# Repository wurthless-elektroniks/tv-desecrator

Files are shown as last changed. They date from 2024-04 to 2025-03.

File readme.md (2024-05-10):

# TV Desecrator: A universal-as-I-can-make-it RGB SCART circuit for non-SCART TVs

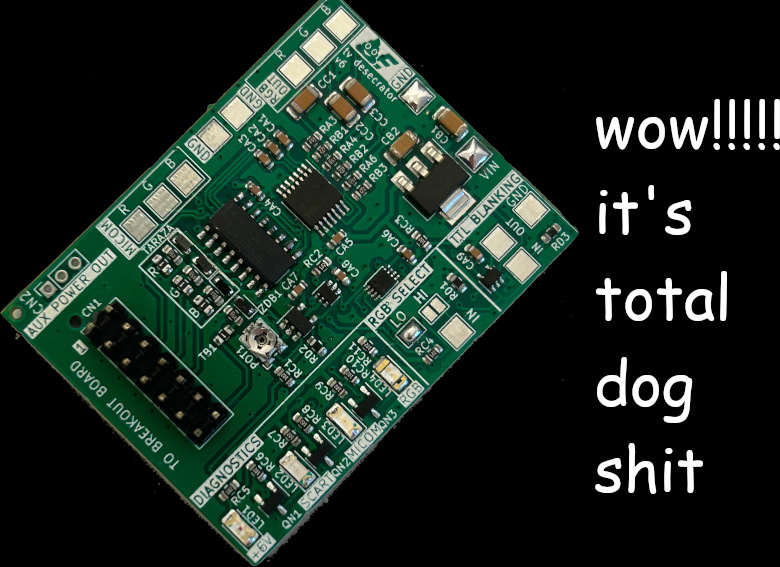
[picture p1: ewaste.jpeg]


Hey, you! Are you an idiot who wishes to ruin a perfectly good TV? Then build yourself a TV Desecrator! It's a reliable way of adding a SCART connector to a TV that doesn't normally support it.

There are plenty of takes on RGB mods already, but I wanted to do one with seamless operation and simpler installation. In other words, I wanted the SCART connector to behave as if it was part
of the TV set rather than a bolt-on feature. A hell of a challenge for someone with next to no knowledge of electronics, but totally worth it in the end as long as I get to stick it to the other
modders and hopefully make a few bucks while I'm at it.

This is all discrete logic so you only get the Gerbers.

The TV Desecrator is part of the wider Jänkermeister's CRT Toolkit project, which also includes:
* The [G1 Crymax](https://github.com/wurthless-elektroniks/g1crymax)
* The [simple SCART breakout board](https://github.com/wurthless-elektroniks/scart-breakout)
* ...and possibly others

# WARNING - STILL UNDER CONSTRUCTION

TV Desecrator v6 is still undergoing testing and is not guaranteed to work correctly. Think of this as an open betatest with nobody participating (except for me).
If you order your own boards and find it doesn't work, then you forgot to read this caveat emptor.

# Features

* SCART port can function exactly like a normal input; totally switchless operation
* RGB injection that doesn't interfere with OSD and other input modes
* Safe and reliable SCART RGB blanking detection: no need to worry about 10 volt signals wrecking shit
* Much easier installation than passive diode mux mods: abacus not required
* THS7374 video amp so the final injected signal comes in loud and clear
* Diagnostic blinkenlights to tell you where you fucked up
* Modular design so you can easily pull the TV case apart when things inevitably explode
* Modular design also means you can use BNC or JP-21 like a civilized person

# **BEFORE YOU INSTALL THIS, ASK YOURSELF: "DO I REALLY NEED RGB?"**

Chances are you don't. People often use RGB to compensate for poorly tuned equipment. You can get a great picture without ever having to use RGB.
To do so, perform some combination of the following steps:

* Recap entire set, particularly anything related to the power supply, horizontal/vertical deflection circuits, RGB drives, and most importantly the NTSC decode circuitry
* Recalibrate colors, drives and cutoffs if possible
* Drop G1 pin to a negative voltage and recalibrate SCREEN and FOCUS to get a sharper picture and better contrast (*this is a must on larger sets!*)
* Use component or S-Video if available (they don't suffer from composite color artifacts)
* Use a console that outputs better quality video than others in its class (in Sega Genesis terms, throw your Model 2 in the garbage and get a Model 1)

Other options for RGB gaming, besides modding old TVs, include:
* Computer monitors that support 15 kHz natively
* The usual 15 kHz to whatever-standard-you-please converters (shitty GBS converters, SCART to component, OSSC, etc.)
* If you want to live dangerously, an arcade monitor with an amp and sync stripper. (Some oldschool consoles output TTL RGB natively, you just need to know how to tap it.)

Remember: **DO NOT RGB MOD A TV SET UNLESS YOU REALLY NEED TO** <sup><sub>(or just want to scam idiot retro gamers)</sub></sup>

# Schematic

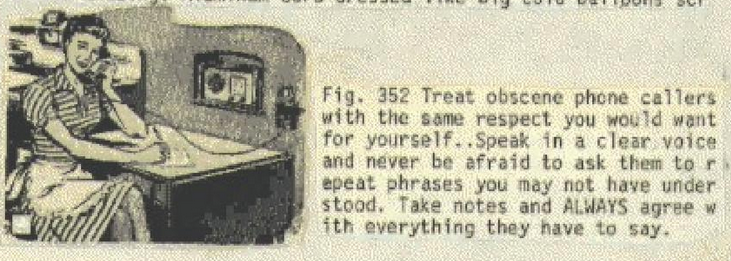
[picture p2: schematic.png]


There are two major parts of the circuit. The first is logic circuitry that determines when the RGB signal coming in from the SCART connector should
be sent to the TV; if not allowed, it selects the MICOM inputs. The second is a switcher and amplification circuit that allows the TV Desecrator
to appear to the TV as if it were a normal, everyday MICOM. The rest is all boring and not worth explaining here.

Please read the extensive documentation to learn about how this thing works, how to install it, and known issues.

## License

Public domain

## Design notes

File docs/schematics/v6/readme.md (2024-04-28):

# TV Desecrator v6 schematics

This is what happens when a guy with a lot of money and no electronics expertise designs a circuit board. I'm writing this to explain how
the circuit works and also why I chose to implement the circuit this way.

## Power supply

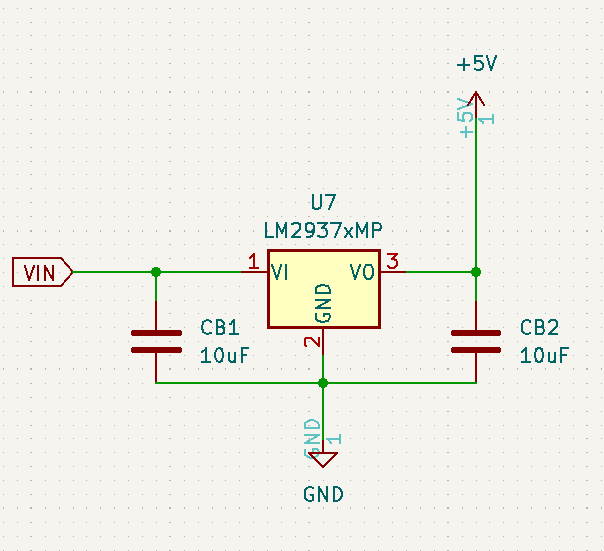
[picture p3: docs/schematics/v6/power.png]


The TV Desecrator runs at +5V. Although many TVs have a +5V rail (or +5.6V) for the MICOM circuit, I've found that the voltage regulators aren't
really meant to drive anything other than a standby load, and, being standby rails, are on all the time. So the TV Desecrator has a voltage regulator
onboard that's tied to some lower-voltage DC doohickery on the chassis. The voltage regulator is a LM2937IMP-5.0 or pin-compatible replacement.
Two 10uF ceramic caps stabilize the voltage going in and out of the regulator. Boring stuff, really.

## RGB inputs

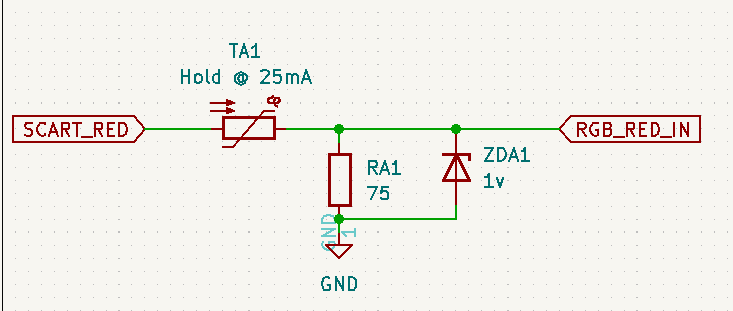
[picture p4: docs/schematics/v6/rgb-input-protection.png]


RGB comes in off whatever device we have, then each channel goes through a PTC resettable fuse, has the 75 ohm pulldown applied, and is forwarded off
to the switcher. A zener (nominally 1V but can be 2V) is used to clamp the signal to ground in case of overvoltage.

Protecting the TV chassis is mission critical, and here's the first line of defense, where I at least try to prevent this. The idea is that if voltages
go too high, then the zeners will start clamping and drawing a few too many milliamps, causing the PTC fuses to stop the show. I had lost one TV to
JAMMA-level voltages and I wasn't about to let it happen again.

## SCART blanking voltage detection

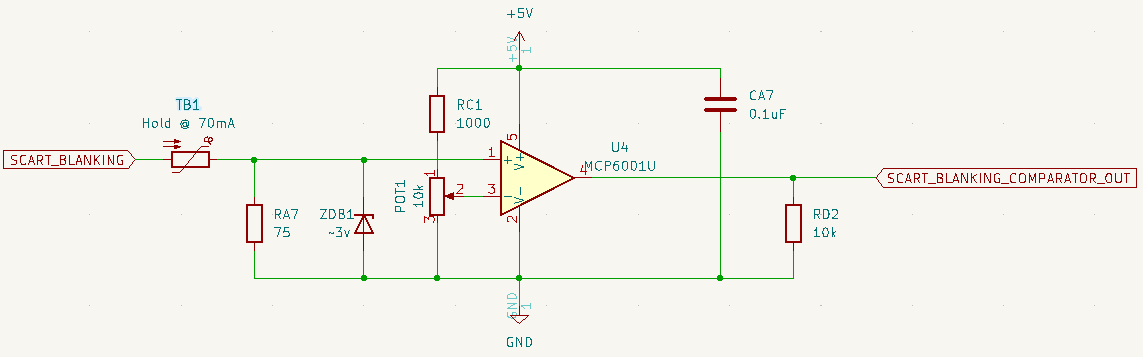
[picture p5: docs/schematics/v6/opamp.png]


This is where things get a little weird. I used an op-amp to detect the SCART blanking voltage mostly because of the odd voltages that could be
coming in on that line. It's supposed to be 75 ohm terminated, which I honored here, but even then the voltage might not be enough to trigger
the CMOS logic. Also, when I did my reading on typical SCART implementations, I read that some systems might use voltages higher than the 1-3VDC
that are typically present on this pin in RGB mode.

The reference voltage for the op-amp is set via a 10k potentiometer. It should be calibrated to as close to 1VDC as possible. Virtually every SCART
spec you'll find online says that a blanking voltage of 1-3VDC indicates RGB.

The blanking signal comes in through another PTC resettable fuse and is 75-ohm terminated, with a zener (nominally 5.6VDC) keeping watch over this
side of the circuit, because anything above 6 volts or so will make the op-amp very sad to the point where it kills itself. Upon going above the
reference voltage (which, again, should be 1VDC), the op-amp outputs a logical high signal; at all other times it is a logical low signal. This
signal is called SCART_BLANKING.

## RGB muxer logic

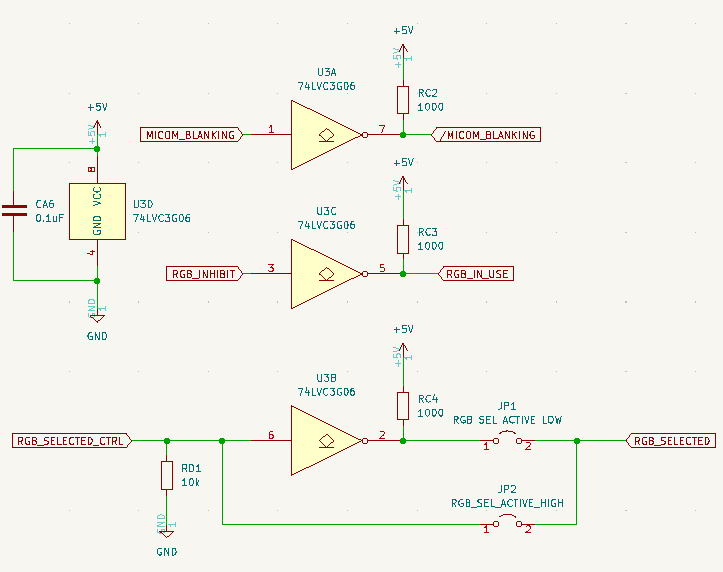
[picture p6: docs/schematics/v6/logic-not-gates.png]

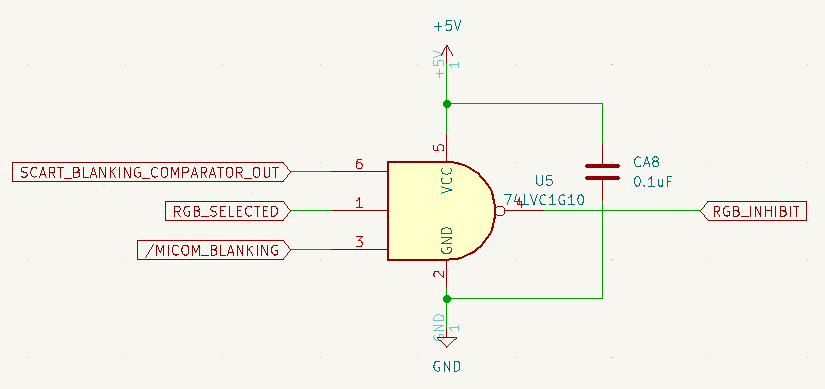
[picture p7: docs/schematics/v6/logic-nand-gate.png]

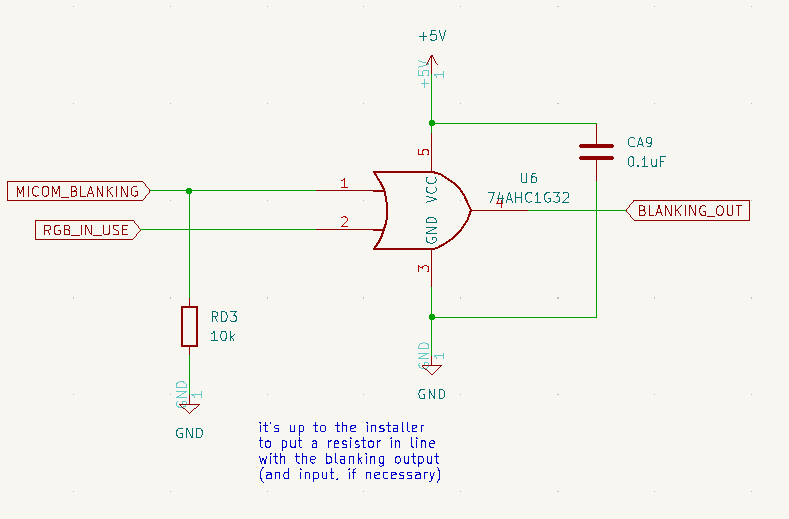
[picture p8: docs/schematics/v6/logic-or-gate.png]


This ratsnest of logic computes:

    RGB_INHIBIT = !(SCART_BLANKING && RGB_SELECTED && !MICOM_BLANKING)
    RGB_IN_USE = !RGB_INHIBIT
    BLANKING_OUT = (RGB_IN_USE || MICOM_BLANKING)

This is done entirely using discrete 74-series logic chips, but could be unified into a single chip. As of yet, though, virtually
every single chip option would either be too expensive, overpowered, unreliable, or not +5VDC compatible.

Of particular interest is the RGB_SELECTED signal. This is a logical input from some other device indicating that the TV is set to the
right input and is ready for our RGB signal. This is something of a departure from other RGB muxer mods, which simply don't implement
this because there are too many cases to account for. That would add complexity, so I simplified it down to a single input and left it at
that. Jumpers on the board set this signal to active high (goes directly to the chips), or active low (input goes via an inverter).

## Switcher phase

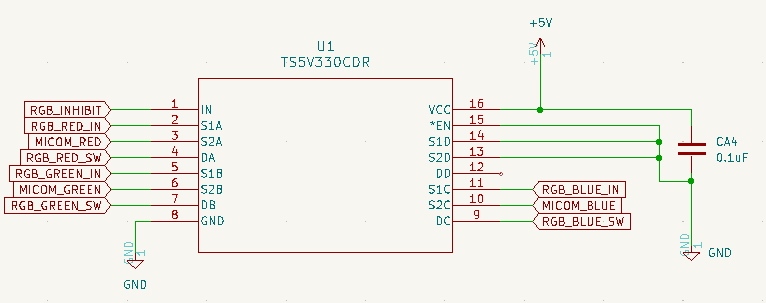
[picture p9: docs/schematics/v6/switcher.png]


RGB switching is performed by a TS5V330CDR 4-channel video switch. By default the switch allows the MICOM signal through, as RGB_INHIBIT
will normally drive the select pin high. When RGB_INHIBIT falls, the injected RGB signal passes through to the final output phase.

## Final output phase

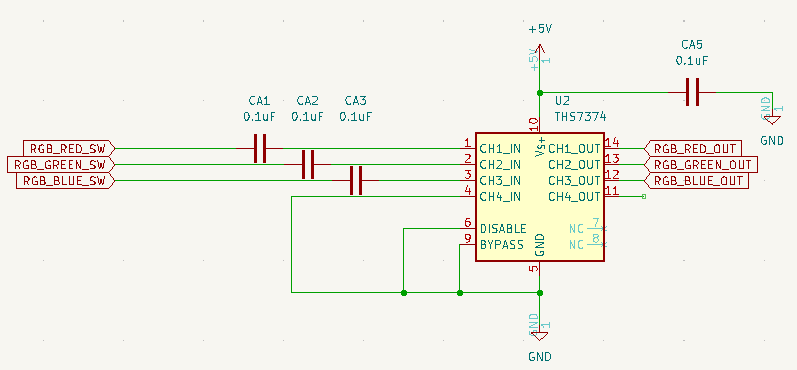
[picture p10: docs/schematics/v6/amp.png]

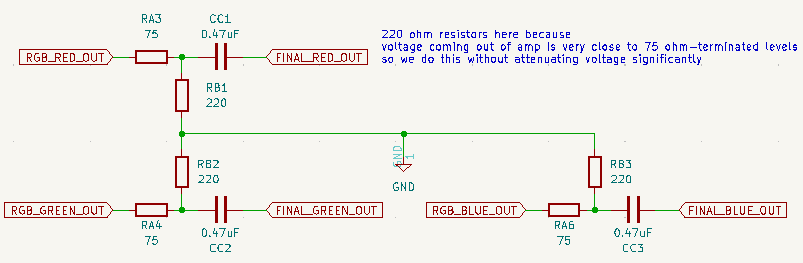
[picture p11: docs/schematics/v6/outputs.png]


The switched video goes through a THS7374, which I'm abusing here as a buffer. Since this circuit is functionally isolated from the
main RGB lines, we have to do the usual 75 ohm pulldown dance and buffer capacitor on the end. The pulldown is 220 ohms, which seems
odd but has been chosen to prevent the output RGB voltages from being halved, as they will be slightly above the 0.7VDC RGB levels by
the time they exit the amplifier. The caps are 0.47uF, chosen because they were a known value in my JVC, but had also been found to work
on other sets.

The THS7374 was originally added to the design because whatever switching logic would be in place would likely attenuate the signal
somewhat. The disable and lowpass features are not used at all; those pins are simply tied to ground. The obvious improvement here
is to replace it with a far cheaper chip, but this is the one I'm used to, so I'm just doing what I know works.

## Diagnostic lights

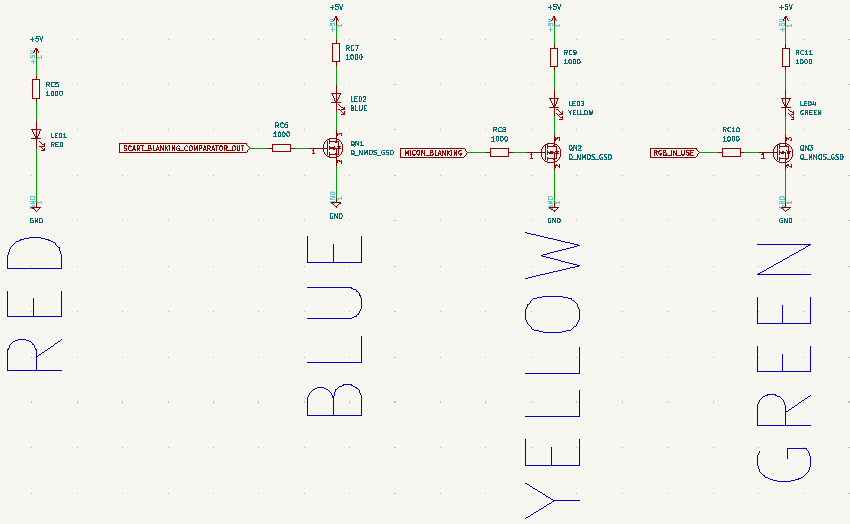
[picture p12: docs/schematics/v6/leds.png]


Finally there are the four diagnostic LEDs. They are:

* RED = +5V (power present)
* BLUE = SCART (SCART blanking signal detected)
* YELLOW = MICOM (MICOM blanking signal detected)
* GREEN = RGB (RGB in use)

All of the LEDs are current-limited using 1k resistors, which is enough to turn them on at non-obnoxious levels. The red LED is on all
the time as it's tied to the power supply. The others are all switched with N-channel MOSFETs so as not to drag the I/O logic low.
It's obvious that this design formerly used NPN transistors as the resistors limiting base current (sorry, *gate* current) are still there.
These resistors are most likely useless now and will be removed in future revisions.

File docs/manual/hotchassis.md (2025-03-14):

# The perils of hot chassis

This is a must-read for anyone attempting to modify any CRT TV or display, as it's important
for health and safety.

The TV Desecrator was designed only for television sets that are properly isolated from the mains.
I didn't really know about the hazards of hot chassis at the time, but now that I do, and have made
a very expensive computer (a Mac Studio) explode as part of this lesson, I'm writing this document to advise all
prospective modders about hot chassis, how to identify them, and the dangers of modifying them.

**The tl;dr is: NEVER attempt to modify a hot chassis. You will kill your expensive equipment and
potentially yourself.**

## What's a hot chassis?

A hot chassis is any CRT chassis where the low voltage side is directly referenced to the mains.
These tend to be seen on older or "budget" designs, where proper isolation is not required and they
assume you won't be fiddling around inside of the set.

## Identifying a hot chassis

Here are some ways of identifying a hot chassis.

1. **No transformer besides the flyback**: This is the easiest way of detecting a hot chassis.
   Trace the low voltage power supply back as far as you can go. If you don't see that it's connected
   to a switching power supply, or that there's a dropper resistor or similar knocking the voltage down
   to something the low voltage regulators can handle, then it's a hot chassis.

2. **RF-only sets**: Not always a sign you're dealing with a hot chassis but a good indicator. RF-only
   sets only need to expose one piece of metal (the RF jack) so the designs aren't concerned at all with
   safely isolating the chassis. **The tell-tale sign is whether the tuner directly terminates with a
   coax connector.** If the coaxial connector is on its own box, then that's a sign the RF input is using
   a balun to isolate the coax lead from the chassis.

3. **Chassis "ground" connected to AC neutral**: Usually on a hot chassis a resistor is all that separates chassis "ground"
   from AC neutral. Check what resistance there is between ground and the AC neutral connection; there shouldn't
   be any. On one Orion set I tested, the resistor separating chassis "ground" and neutral was approximately 16k ohms.

Note that on switching power supplies, there may be class Y capacitors tying the supposedly isolated side
with the mains. This is normal. 

## Hazards

If you attempt to modify or otherwise play with a hot chassis, you run the risk of the following:

* Any equipment you connect, including your treasured and very expensive electronics or test equipment, will likely explode
* Electrical shock and possible electrocution
* Smoke and fire

## What if I want to make a hot chassis safe?

That's not worth the cost. You'll need to isolate pretty much every input from the SCART connector, so that's
4 video signals plus two audio signals. Combine that with the fact you need specialist baluns for isolation
and you'll have a sizeable bill.

This is also the reason why you shouldn't try modifying a RF-only chassis to support RCA inputs. I had to give
up on that dream when I realized it wasn't feasible compared to SCART modding.

Save yourself the headache and find a properly isolated set.

**If, however, you ever need to work on a hot chassis as part of a repair job, an isolation transformer and
battery-operated equipment will limit the risk of zaps, ouchies and kabooms.**

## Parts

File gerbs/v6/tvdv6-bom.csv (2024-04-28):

Item | Qty | Reference(s) | Value | LibPart | Footprint | Datasheet | DNP | LCSC
1 | 9 | CA1, CA2, CA3, CA4, CA5, CA6, CA7, CA8, CA9 | 0.1uF | Device:C | Capacitor_SMD:C_0603_1608Metric | ~ |  | C30926
2 | 2 | CB1, CB2 | 10uF | Device:C | Capacitor_SMD:C_1206_3216Metric | ~ |  | C2911380
3 | 3 | CC1, CC2, CC3 | 0.47uF | Device:C | Capacitor_SMD:C_1206_3216Metric | ~ |  | C518885
4 | 1 | CN1 | SCART RGB CTL | Connector_Generic:Conn_02x07_Odd_Even | Connector_PinHeader_2.54mm:PinHeader_2x07_P2.54mm_Vertical | ~ |  | C71397
5 | 1 | CN2 | AUX POWER | Connector_Generic:Conn_01x03 | Connector_PinSocket_2.00mm:PinSocket_1x03_P2.00mm_Vertical | ~ |  | C18723059
6 | 1 | JP1 | RGB SEL ACTIVE LOW | Jumper:Jumper_2_Open | Jumper:SolderJumper-2_P1.3mm_Open_Pad1.0x1.5mm | ~
7 | 1 | JP2 | RGB_SEL_ACTIVE_HIGH | Jumper:Jumper_2_Open | Jumper:SolderJumper-2_P1.3mm_Open_Pad1.0x1.5mm | ~
8 | 1 | LED1 | RED | Device:LED | Diode_SMD:D_1206_3216Metric | ~ |  | C273626
9 | 1 | LED2 | BLUE | Device:LED | Diode_SMD:D_1206_3216Metric | ~ |  | C965827
10 | 1 | LED3 | YELLOW | Device:LED | Diode_SMD:D_1206_3216Metric | ~ |  | C93094
11 | 1 | LED4 | GREEN | Device:LED | Diode_SMD:D_1206_3216Metric | ~ |  | C2980185
12 | 1 | POT1 | 10k | Device:R_Potentiometer | Potentiometer_SMD:Potentiometer_Bourns_TC33X_Vertical | ~ |  | C719176
13 | 3 | QN1, QN2, QN3 | Q_NMOS_GSD | Device:Q_NMOS_GSD | Package_TO_SOT_SMD:SOT-23-3 | ~ |  | C414015
14 | 7 | RA1, RA2, RA3, RA4, RA5, RA6, RA7 | 75 | Device:R | Resistor_SMD:R_0603_1608Metric | ~ |  | C325592
15 | 3 | RB1, RB2, RB3 | 220 | Device:R | Resistor_SMD:R_0603_1608Metric | ~ |  | C269445
16 | 11 | RC1, RC2, RC3, RC4, RC5, RC6, RC7, RC8, RC9, RC10, RC11 | 1000 | Device:R | Resistor_SMD:R_0603_1608Metric | ~ |  | C3017736
17 | 3 | RD1, RD2, RD3 | 10k | Device:R | Resistor_SMD:R_0603_1608Metric | ~ |  | C2074749
18 | 3 | TA1, TA2, TA3 | Hold @ 25mA | Device:Thermistor_PTC | Resistor_SMD:R_0603_1608Metric | ~ |  | C883088
19 | 1 | TB1 | Hold @ 70mA | Device:Thermistor_PTC | Resistor_SMD:R_0603_1608Metric | ~ |  | C883088
20 | 1 | TP1 | MICOM RED | Connector:TestPoint | TestPoint:TestPoint_Pad_2.5x2.5mm | ~
21 | 1 | TP2 | MICOM GREEN | Connector:TestPoint | TestPoint:TestPoint_Pad_2.5x2.5mm | ~
22 | 1 | TP3 | MICOM BLUE | Connector:TestPoint | TestPoint:TestPoint_Pad_2.5x2.5mm | ~
23 | 1 | TP4 | BLNK IN | Connector:TestPoint | TestPoint:TestPoint_Pad_2.5x2.5mm | ~
24 | 1 | TP5 | BLNK OUT | Connector:TestPoint | TestPoint:TestPoint_Pad_2.5x2.5mm | ~
25 | 1 | TP6 | VIN | Connector:TestPoint | TestPoint:TestPoint_Pad_2.5x2.5mm | ~
26 | 1 | TP7 | RGB SELECTED | Connector:TestPoint | TestPoint:TestPoint_Pad_2.5x2.5mm | ~
27 | 1 | TP8 | FINAL RED | Connector:TestPoint | TestPoint:TestPoint_Pad_2.5x2.5mm | ~
28 | 1 | TP9 | FINAL GREEN | Connector:TestPoint | TestPoint:TestPoint_Pad_2.5x2.5mm | ~
29 | 1 | TP10 | FINAL BLUE | Connector:TestPoint | TestPoint:TestPoint_Pad_2.5x2.5mm | ~
30 | 4 | TP11, TP12, TP13, TP14 | GND | Connector:TestPoint | TestPoint:TestPoint_Pad_2.5x2.5mm | ~
31 | 1 | U1 | TS5V330CDR | TS5V330CDR:TS5V330CDR | TS5V330CDR:D16 | TS5V330CDR |  | C2652482
32 | 1 | U2 | THS7374 | Amplifier_Video:THS7374 | Package_SO:TSSOP-14_4.4x5mm_P0.65mm | https://www.ti.com/lit/ds/symlink/ths7374.pdf |  | C2652746
33 | 1 | U3 | 74LVC3G06 | 74xGxx:74LVC3G06 | Package_SO:VSSOP-8_2.4x2.1mm_P0.5mm | http://www.ti.com/lit/sg/scyt129e/scyt129e.pdf |  | C548744
34 | 1 | U4 | MCP6001U | Amplifier_Operational:MCP6001U | Package_TO_SOT_SMD:SOT-23-5 | http://ww1.microchip.com/downloads/en/DeviceDoc/21733j.pdf |  | C21403
35 | 1 | U5 | 74LVC1G10 | 74xGxx:74LVC1G10 | Package_TO_SOT_SMD:SOT-363_SC-70-6 | http://www.ti.com/lit/sg/scyt129e/scyt129e.pdf |  | C460523
36 | 1 | U6 | 74AHC1G32 | 74xGxx:74AHC1G32 | Package_TO_SOT_SMD:SOT-353_SC-70-5 | http://www.ti.com/lit/sg/scyt129e/scyt129e.pdf |  | C460492
37 | 1 | U7 | LM2937xMP | Regulator_Linear:LM2937xMP | Package_TO_SOT_SMD:SOT-223-3_TabPin2 | http://www.ti.com/lit/ds/symlink/lm2937.pdf |  | C42249
38 | 3 | ZDA1, ZDA2, ZDA3 | 1v | Device:D_Zener | Diode_SMD:D_0603_1608Metric | ~ |  | C7081529
39 | 1 | ZDB1 | ~3v | Device:D_Zener | Diode_SMD:D_0603_1608Metric | ~ |  | C7403907

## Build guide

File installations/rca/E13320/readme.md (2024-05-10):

# RCA E13320

Lovely 13" slot mask TV from RCA.

Tube: 37GDA86X (slot mask)

Points of interest:
- CV505, CV507, CV509 are the RGB caps
- RR40: Red channel TTL-to-0.7V dropdown resistor
- RR39: Green channel TTL-to-0.7V dropdown resistor
- RR38: Blue channel TTL-to-0.7V dropdown resistor
- RR41: Blanking resistor

Switchless operation only possible via sync comparison or I2C snooping.

[Sunthar's diode mux diagram](https://sector.sunthar.com/guides/crt-rgb-mod/rca-e13320.html) was a big help here.

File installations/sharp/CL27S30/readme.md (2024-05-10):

# Sharp CL27S30

Consumer grade TV with S-Video, two video inputs, and picture-in-picture.

Tube: Thomson A68ADT25X-06 (shadow mask)

Points of interest:
- C804 = red capacitor
- C805 = green capacitor
- C806 = blue capacitor
- Jumper 417 = blanking from MICOM to jungle IC
- C408 = 7 volts smoothing cap

Switchless operation still TODO.

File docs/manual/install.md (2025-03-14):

# Installation

## Identifying a RGB-capable set

Find a CRT TV matching these specifications:
- Manufacture date in the 1990s or 2000s
- Must have composite video input, **preferably only one video input**
- Must have on-screen display
- Sets with component and composite on the same video input are of particular interest (I'll explain why)
- **Chassis MUST be properly isolated from the mains (read [hotchassis.md](hotchassis.md)). NEVER attempt to
  modify a hot chassis.**

Once you have found your TV of choice, open it up and study the circuitry. You are looking for the following:
- MICOM chip: a microcontroller looking thingy near the front panel controls.
  It receives power in standby (typically +5V) and will have an integrated RGB video output.
  Near the MICOM, you will find...
- TTL to 0.7V (1Vpp) RGB conversion circuit, which is usually nothing more than three voltage dividers
  for each of the RGB channels. Usually identifiable by a trio of 4.7k resistors close to the MICOM.
- The blanking control circuit, which the MICOM chip uses to take priority over the NTSC output.
  This is typically +5V at the source, but is often knocked down to a lower voltage.
- The RGB in-line capacitors. There will be three of them, and they will all be the same value.
  In many cases they will be surface mount caps right next to the inputs on the jungle chip.
  However it's common for these caps to be electrolytics.
- And, most importantly, the jungle chip, which is an all-in-one chip that decodes NTSC signals,
  overlays the OSD, and drives the RGB signals on the CRT itself.

The TV Desecrator is NOT compatible with the following types of TV chassis:
- All-in-one MICOM/jungle chip with no external RGB inputs
- MICOM logic operating at 3.3VDC (the TV Desecrator assumes 5VDC)
- Jungle chips that use "digital" RGB inputs, or any RGB signal that isn't 0.7V

**TVs from the 1980s and earlier will NEVER be supported.** Their circuitry is all analog, the picture they
produce is inferior to the more modern sets, and they have massive retro and collector appeal that will be
dashed the second you graft a SCART connector onto them. Plus which, RGB video can't be used to drive
the electron guns directly. Leave those sets for the collectors and restoration guys. They'll thank you for it.

Note that some TVs have composite and component signals coming in on the same video input (Toshiba sets call
the input "COLOR STREAM"). The jungle chip on those sets *might* have a pin that toggles the component lines
between YPbPr and RGB. **These sets aren't supported by this mod, but I might tackle them as a separate project one day.**

And, most importantly, **test your TV in full before modding it!** That way you'll know how it's supposed to work.

## Testing procedure

Before you hack apart your TV, you'll need to test it in full. If you have the remote control, that's great news because you'll be
able to go into service menus if your set has any.

Connect as many video sources as possible to see how the set behaves with a given input. Play around with some games to try
to get the image to distort. Make notes on how every OSD screen behaves. Take pictures and video if need be.

Also check how audio input is handled with RCA stereo connections. When you have only the left channel plugged in, does it play
over both speakers? If you connect a dummy input to the right channel input, does the right channel mute?

**Remember: All of the information you gather before even opening the set will help you in the long run.**

## Forming the plan of attack

By the time your TV is in pieces on the floor of your studio apartment and you've gotten to this sentence,
you have without a doubt have read the schematics. Thus you will know that **the TV Desecrator sits between the
MICOM and jungle chips, allowing RGB in from a SCART video source when it is allowed**. This provides the
challenge that you now face during the installation.

The general installation procedure is:

- The **TTL-level (+5V) blanking signal** must be rerouted to the TV Desecrator, and the TV Desecrator's mixed blanking
  signal must be returned in its place. There is typically a resistor limiting current from the MICOM's blanking pin
  to the jungle chip's input, usually around 1.5k to 2k. Measure this resistor, then put an equivalent resistor in line
  from the TV Desecrator's blanking output. Failure to do this will cause problems, such as OSD colors/black levels being
  incorrect.
- The **0.7V-level RGB signals prior to the capacitors** must be rerouted to the TV Desecrator, and the TV Desecrator's
  multiplexed RGB signals must be returned to the opposite end of where the capacitors formerly sat.
- A suitable DC power source must be located to power the 5 volt voltage regulator on board the TV Desecrator. Though many
  sets have a +5V power source, it's designed only to run the MICOM and is on all the time (i.e., in standby).

The TV Desecrator does not carry composite video or audio, but you'll have to get them out of the SCART connector and route
them as follows:
- The composite video signal must go to the composite video input. This is trivial. I don't even know why it was worth mentioning.
- The audio inputs must go to the... well, the audio inputs. If your set is mono, mix the two guys together with resistors.
  If your set stays in mono mode no matter what you do, it's because the RCA jacks have an internal switch that is toggled when
  you stick something in there. You might need to hack the RCA connectors to get around this limitation.

This is difficult already, but now you have to deal with the most annoying thing of all...

## Knowing when to inject RGB

Also called "why every RGB modder just uses a switch".

RGB_SELECTED is a signal that, when active, will get the TV Desecrator injecting RGB video. It can be set as
active high (jump HI) or as active low (jump LO); the input is always pulled low via a 10k resistor.

Recall that RGB video is injected if and only if:
- 1. the SCART blanking signal has been detected,
- 2. the MICOM is not displaying anything (MICOM_BLANKING is low), and
- 3. RGB_SELECTED is active (somehow)

Or, in boolean terms:

    RGB_IS_ACTIVE = !RGB_INHIBIT = !(SCART_BLANKING && !MICOM_BLANKING && RGB_SELECTED)

So how do you find the RGB_SELECTED signal? Here are some ideas.

### Trivial difficulty: Always on

Jump LO and let RGB_SELECTED float. Pulldown resistors will do their job. RGB will always be injected
as long as conditions 1. and 2. are met. And that will obviously cause interference when you switch video inputs.

In short, this makes the TV Desecrator behave like a normal diode mux mod. 

### Easy difficulty: The Switch of Shame

To defeat the purpose of this being a switchless mod, or to force RGB off, you may add a switch somewhere.
How you choose to do it is up to you:

- Switching the SCART blanking signal (with a switch on the breakout board or somewhere inbetween)
- Switching RGB_SELECTED between +5V and ground

This will still cause problems when you switch video inputs, but at least you have slightly more control over
when the thing injects RGB.

You're also free to add a three-setting toggle switch with ON, AUTO and OFF positions that allows you to force RGB on (pulled up)
or off (pulled to ground), or to fallback to automatic mode (using the SCART blanking signal received at the SCART connector).
**Just be careful that the SCART blanking signal you feed to the TV Desecrator stays within 1-3VDC!**

### Medium difficulty: Sync signal comparison

Jungle chips typically have a composite video output signal either because there's a video output on the
back of the TV, or the signal needs to be routed to the MICOM so that it can display closed captions.
Using two sync strippers and a microcontroller, you can easily match up the sync pulses on the composite
signals and generate the RGB_SELECTED signal as appropriate.

### Hard difficulty: MICOM I/O pins

Some TV manufacturers had the decency to have their MICOM programs output a status indicator on the GPIOs.
If you can find an active high or active low signal that reliably indicates when the video input of your
choice is selected, you can use that. Schematics, and occasionally 74-series logic chips, will be your
best friend here.

### Nightmare difficulty: I2C bus schenanigans

Virtually all CRT TVs use the I2C protocol for communications between the MICOM and other components, including the jungle
chip and RF tuner. Pick a suitable I2C target, study its protocol, and write a simple microcontroller program to produce
RGB_SELECTED. You can then have the MCU sit on the bus as a sniffer, or to act as an intermediary.

This, however, is far easier said than done. The I2C bus is extremely fragile and tampering with it will cause you
far more headaches than it's worth. It's a mission critical part of the TV set and if it isn't working correctly you
will cause major problems.

Examples of what can happen when you tamper with the I2C bus:
* TV won't even turn on
* MICOM locks up and the TV becomes totally unresponsive
* MICOM runs normally but the RGB drives are totally dead

I2C is ancient technology from the 1980s, it's too susceptible to noise and interference, and if you're missing a pullup
somewhere it will shit the bed. So don't play with it unless you want to spend day after day cursing at an ancient TV set.

### Impossible difficulty: Hacking the MICOM program

All MICOMs you'll find in CRT TVs will use mask ROMs. However, it's likely that the same ROM is shared between different models
of TV, with the EEPROM containing model-specific configuration loaded at startup. Nefarious hackers could try to modify the program
such that normally unused I/O lines on the MICOM could be made to output the RGB_SELECTED signal. This is hugely ad hoc-y though
and I doubt it's even possible to do because MICOM documentation is hard to find.

## Recalibration

Once you've powered your TV on and made sure everything works, you'll need to recalibrate colors.
You must do this for both composite video and for RGB video.

Typical recalibration involves the following:
- Generate a test pattern somehow. If you're a cheapskate, you can just use one of the OSD menus.
- Set SCREEN to minimum on flyback, then, with RGB active, start increasing until your test pattern is nice and bright.
- If you can get into the service menus, recalibrate RGB gain and cutoffs. Older sets have these as potentiometers on the boards.
- Switch over to composite and begin tweaking brightness, contrast and hue settings. The jungle chip usually won't apply any
  of these to the RGB signal, they're for NTSC only.

Now all you need to do is install the breakout board and you're done. I won't cover that, obviously, because that's a lot
of work with Dremels and screws and whatnot.

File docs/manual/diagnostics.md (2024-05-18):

# Diagnostics and troubleshooting

## Blinkenlights

There are four blinkenlights on the TV Desecrator board. Here is what they mean.

* Red: +5V present. Board is receiving power. The board should only power on when the TV is "on" (i.e., not in standby).
* Blue: SCART RGB blanking signal detected.
* Yellow: MICOM blanking signal active. This must turn on or blink when the TV's OSD is active.
* Green: SCART RGB injection signal active.

Intended operation:

* Red only means the board is powered.
* Yellow should always light up when the OSD is on.
* Green should only light up when Blue is on.
* Yellow and Green should never light at the same time, except when the OSD is active.

## Troubleshooting

Here are some problems I've encountered and their causes.

### No power (red light stays off)

The TV Desecrator needs a 6-12 volt power source. The jungle chip is usually supplied with approximately 7 volts.

There is no reverse polarity protection on this circuit, by the way. You'll destroy it, and possibly your equipment,
if you don't feed a positive voltage to VIN.

### Red light is on when the set is off

You've tapped off a power rail that's turned on in standby. Find another one, or live with the milliamps of wasted electricity.

**If the TV Desecrator fails catastrophically while running in standby mode, then I take no responsibility for your installation mishaps.**

### Picture looks exactly like composite

That's probably because it is. The TV Desecrator falls back to composite over SCART if it sees no RGB blanking signal.
Make sure the blue and green diagnostic lights toggle.

### Black screen, but image barely visible when SCREEN/brightness turned up all the way

This is most likely the underlying composite video signal bleeding through. The MICOM blanking line is likely stuck high
or the SCART cable isn't outputting RGB video.

### SCART RGB signal detected but RGB never injects

RGB_SELECTED isn't going active. Green diagnostic light should be toggling. Logic chips might be bad.

### RGB injects all the time

Immediately disconnect power and check for bridged solder joints.

You might also have set the calibration potentiometer too low. Turn the pot all the way to the left and recalibrate.

### Ghosting

You're missing pulldown resistors on the RGB lines.

Missing pulldowns on the input result in extensive ghosting. This will happen on the output side too, but not quite as messy.

### Inverted colors

Probably swapped wires somewhere. RGB lines are often creatively routed on the chassis, so it's not often clear which lines are which.
Check schematics and try again.

### Odd colors

You probably didn't connect the RGB lines correctly or have a short somewhere. Examples include:

* Yellow/blue colors = red/green lines shorted

### Screen is too dark

This can be caused by resistance or capacitance anywhere on the inputs and outputs.

Capacitance on the output side will result in video that is too dark but slowly fades in after a while. If this happens, CC1/CC2/CC3
all need to be changed. They are 0.47uF by default; use a lower value if you want.

Any resistance on the input can cause the signal to be weakened because of the 75 ohm pulldowns. This is why there's an RGB amp on
the board in the first place: the signal is bound to be attenuated by the protection circuitry, particularly the thermistors.

### Dark screen with dotted highlights

Unwelcome pulldown on output side

### Screen is way too bright

RGB line voltage is too high. Put resistors inline to darken the picture.

**TTL-level RGB is the kiss of death for your TV chassis.** The TV Desecrator attempts to prevent you from frying your TV, but it will
likely sacrifice itself in the process. Some overvoltage/overcurrent protection is there, but it's only there to prevent
bozos from feeding anything into the TV that is way out of spec.

### OSD has missing colors or backgrounds

I've found in testing that the blanking signal from the MICOM can be a little finicky.

My JVC has an odd blanking circuit where the blanking signal is routed in parallel between a 47pF capacitor
and a 1800 ohm resistor. Replacing this with a single 1k resistor caused issues. The OSD no longer showed
red or yellow colors (whites were fine), and the black backgrounds of menus/volume controls no longer displayed.
If I can fix this in the future, I'll document it here.

### No picture on Nintendo 64 even though RGB is being injected

The N64 needs to be modded to support RGB. Install the mod and try again.

This will also happen if your SCART cable has the RGB blanking signal active but your console doesn't output RGB.
All SCART cables are "dumb" in that they will always signal that they are RGB cables without actually checking if
RGB video is present.

### Unwelcome video noise

There are several possible causes:

- Composite video causing background interference. Try a sync stripper.
- Your SCART cabling sucks. Try other consoles, cables, etc. to isolate the problem.
  Lots of Chinese-made SCART cables tend to be cheapo.
- RGB wiring inside your TV is capacitively coupling to something else. TV chassis cause a lot of noise.
  Try decoupling the wires to ground somehow (twisted pair, shielded wiring, etc.).

### MICOM blanking signal is stuck low or high, inhibiting RGB injection

Check continuity between the MICOM blanking input and muxed output. If it shows continuity, you have a short circuit,
and the OR gate that generates the output blanking signal is feeding back into itself. Doublecheck your wiring and
make sure you haven't removed the wrong component by accident.

### MICOM blanking signal is never detected but RGB blanking works

Press a button you know will trigger the OSD and measure the voltage on the OSD blanking input.
If the voltage is below a TTL logical high (i.e., 3 volts), then you're tapping off the MICOM blanking
signal way too late for it to be effective.

**In this setup, you're most likely feeding too high a voltage to the jungle chip's blanking input.** Modders occasionally
suggest that you can just feed 5 volts to that pin and nothing bad will happen. How the jungle blanking circuit works
internally is that there is usually a PNP transistor on that input that, when any positive voltage is present, enables
the RGB overlay. While this works, there's no real guarantee that transistor will cooperate long term as the base-emitter
voltage will be several times higher than normal.

There are some TVs in which it's not practical to redirect the blanking signal until it's too late. RCA GemStar-enabled
TVs have the MICOM integrated into a separate module, and by the time the MICOM blanking signal is on the chassis PCB
it's already been knocked down to around 1.08 volts. A bodge board is planned as a workaround.

### Injected RGB picture off-center

This is normal. The OSD is calibrated at the factory to display only at a certain position.
If it bothers you, change settings in service mode (if possible).

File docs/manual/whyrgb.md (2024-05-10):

# So why don't TVs have RGB connectors (or that they do)?

Long story short: analog television standards. Televisions were never meant to do anything other than receive programs. 
This only really changed because the market did.

Color TV tubes have worked on the RGB color space from the very beginning, but the problem is that sending RGB signals
over the air is not feasible, and it especially wasn't back in the 1950s when the NTSC standard was adopted. NTSC
set the tone for all analog color standards after, in that the signal needed to be compatible with monochrome sets
and needed to transmit color in the most bandwidth-efficient way possible.

RGB only really became relevant on the consumer end for two reasons:
1. Digitally-generated signals, as from computers and video game consoles
2. France (*those fuckers again*)

A lot of early home computers generated RGB directly but were forced to output composite video because it turns out that
the average consumer didn't want to buy an expensive monitor just to use their shiny new Apple II[^1]. Televisions were never
intended to be computer monitors; they ended up being repurposed.

It was around this time that the SCART standard came onto the scene, not just because of all these devices outputting
native RGB, but because the French were so proud of themselves that they went with the SECAM standard while the rest
of Europe went with PAL. If someone from France bought a PAL video game console, they'd find it was incompatible with
their SECAM TV. So they'd either have to buy an inferior SECAM version (if one was even available) or find a PAL converter.
It's the same case with VHS: PAL videotapes aren't compatible with SECAM TVs, even though both standards are 50 Hz.

Having RGB on the SCART connector killed both of these issues with one stone. Consoles could simply output RGB to a
French TV without having to deal with different encoding schemes, and PAL/RGB conversion[^2] (or even NTSC/RGB conversion)
could easily be done on a single chip.

So why, after all this, did we end up with S-Video and YPbPr?
- S-Video was a videotape standard (and thus limited by videotape bandwidth)
- YPbPr was three signals as opposed to analog RGB, which usually[^3] requires four (R/G/B/CSYNC) or five (R/G/B/HSYNC/VSYNC),
  and could be carried over normal RCA connectors

SCART (and thus RGB) never really won out anywhere other than Europe and maybe some places in Asia. It showed up on some high-end American
sets but didn't support RGB and was dropped fairly quickly. The Japanese repurposed the SCART connector for a similar standard
but changed the pinout of it for some reason. 

Analog video sucked and that's why HDMI replaced it. All these incompatible standards were replaced with a single one
and nobody had to worry about this bullshit ever again. Except if they're retro gamers or anyone dealing with CRTs,
in which case this shit will never end.

[^1]: The Apple II actually output directly to composite because it was cheaper for Apple to implement.
[^2]: This is actually what the French model NES does: it outputs PAL video natively, which is then transcoded to RGB.
[^3]: Sync-on-green was a Sony effort that the rest of the industry didn't adopt because it wasn't compatible with most RGB equipment.

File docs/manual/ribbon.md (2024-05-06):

## Ribbon connector

The TV Desecrator connects to the input device via a 14 pin ribbon connector (2x7 2.54mm).
Though designed mainly with SCART inputs in mind, the ribbon connector can just as easily accept
video from a BNC input (with the appropriate circuitry in place, of course!).

The pinout is as follows:

| Fcn | Pin | Pin | Fcn |
| ---: | --: | :-- | :--- |
| +5V | 1 | 2 | +5V |
| GND | 3 | 4 | GND |
| GND | 5 | 6 | RED |
| GND | 7 | 8 | GREEN |
| GND | 9 | 10  | BLUE |
| GND |  11 | 12  | GND |
| RGB IN USE |  13 | 14  | SCART BLANKING |

where:

* +5V is 5VDC from the TV Desecrator's 5 volt regulator
* GND is chassis ground
* RED/GREEN/BLUE are 0.7 Vpp, 75-ohm terminated RGB video signals
* RGB IN USE is a 5 volt TTL signal, active high, indicating that the TV Desecrator is pulling RGB video from this connector. This signal will
  toggle when the OSD is running, so any logic relying on this pin should have a timeout mechanism so that it stays active.
* SCART BLANKING is exactly what it says on the tin. This is a 75-ohm terminated input, and once the pulldown has been applied, the TV Desecrator
  needs to see a certain voltage (ideally 1VDC) present on this pin before it can inject RGB. **Do NOT directly supply 5V to this pin** -- use a 470 ohm
  resistor.

This connector was formerly 16 pins and carried composite video and audio signals with it. However, they were left off the board as the TV Desecrator
didn't do anything with them. It's up to the breakout board to handle those things. We're only the RGB injector.

Notice also how most of those connections are ground. That's done in an attempt to prevent parasitic capacitance from interfering with the RGB signal
on its way to the TV Desecrator. You can also use twisted-pair ribbon cable here if you feel like it.

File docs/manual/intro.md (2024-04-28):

# Why even bother doing this?

Once upon a time, there were video game consoles that output composite video natively and thus the games were appropriately designed with composite
video and shitty consumer grade NTSC CRT TVs in mind. Then emulation happened and suddenly people thought, "hey, this thing looks better on my computer
than it does on my TV". Thus everything was ruined forever and CRT technicians were cursed with the worst kind of customer: the RGB Retro Gamer.

The RGB Retro Gamer is the CRT repairman's equivalent of an audiophile: a moron who insists on having his retro consoles look exactly like they do in an emulator.
He is a fool who is very easily parted from his money, which was a major reason why I decided to make this. He demands that his TV have RGB inputs (normally only
used on professional-grade equipment and arcade monitors) so that he can get as clear a picture as possible from consumer-grade equipment. This is why he insists
that technicians install the worst connector of all time to his TV. It is a single syllable that strikes fear into the hearts of sane people.
Yes, we have to talk about SCART.

SCART is as big of a French fuckup as existentialism, the auteur theory, the Magniot line, wine tasting, the SECAM color system, Marcel Duchamp, King Louis XVI,
and France itself. Yet it is the only widely accepted consumer-grade 15 kHz RGB video standard because nobody bothered to come up with a better one. In particular,
RGB Retro Gamers insist on using SCART because virtually all console RGB cables use it. If I were to use BNC like a sane person (it's what the PVM users do, anyway),
the RGB Retro Gamer would scowl at me and I wouldn't be able to make money. So, unfortunately, I must appease the fascists and design a circuit centered around
a cumbersome connector that is not widely available in civilized parts of the world and instead must be ordered from companies named Shenzhen Bongfong Precision Electronic Co. Ltd.
and arrive ten months later having been routed through Estonia of all places.

The majority of SCART mods you see online involve weird muxers, hardwired switches and all sorts of crap that I didn't want to bother with. I was more interested
in adding the SCART port to TVs in such a way that the SCART port functions exactly like a normal port on the TV. Unfortunately, this adds a ton of logic, and I'm
a noob at electronics, so the resulting circuit is convoluted, but it at least works with the TVs I've tried it on, which is why I'm releasing it.

# Prior (f)Art

RGB mods have been around for a while. They typically take on one of the following forms:

* **Switch of Shame**: A switch is used to force SCART blanking on so that RGB coming into the TV is always displayed. This may or may not
  cause problems with the OSD, which is why most installs typically use...
* **Passive mux**: Diodes and resistors are used to mix signals together, allowing the OSD to be used while RGB is being injected. While
  it's still better than the Switch of Shame mod, the OSD blanking signal is merely mixed with the RGB blanking signal, resulting normally
  black backgrounds in menus being filled in with the background RGB video. Any installer worth a damn usually uses the passive mux mod.
* **Active mux**: Similar to the passive mux, only a video switch IC does the work. The OSD takes priority, so if the MICOM blanking signal
  goes active, the injected RGB signal is blocked.

So what do these all lack?

* **Simple-as-possible installation**: Unfortunately, RGB mods will always be difficult to do. There's too many factors involved for it to be a straight
  up easy job. However, certain bits could be simplified, particularly not having to pick random resistors, diodes and capacitors.
* **RGB signal interfering with other video inputs**: Modders like to assume that your TV will never leave the RGB input, or that you'll
  nicely switch off your RGB device before switching back to RF or to another composite/component input. This will obviously cause interference
  when you do, because the RGB video will keep being fed into the TV, but not synced correctly.
* **Input protection**: So many of these RGB mux mods lack critical overvoltage/overcurrent/ESD protection on their inputs, leaving the TV
  exposed to danger.

The TV Desecrator attempts to solve these problems, and probably fails at doing so. Guess it's the thought that counts.

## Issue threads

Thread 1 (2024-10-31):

Using this to input analog RGB into a PVM/CRT that has only TTL RGB

bassybeats, 2024-10-31:
Could this be used to inject analog RGB into a TTL PVM? I have a JVC-TM90PSN that only has TTL RGB/CGA in. But if you look at the schematics it looks like it gets converted internally back to analog RGB.

TTL is useless for me so was thinking this project might/could work?

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

wurthless-elektroniks, 2024-11-01:
This isn't the mod you're looking for. The TV Desecrator is only meant to multiplex 0.7Vpp-level analog video and not TTL video.

Looking at the schematic, it appears that what you're trying to do is inject RGB video onto the main RGB line drives, which connect directly to the neckboard. This is dangerous and you should never try doing this. (I have a Sony PVM that is composite only and can't be modified except through this method, which is why I won't mod it.)

The following is merely guesswork and not actual advice.

The 74LS09 is an AND chip being abused as a buffer. I think this is strictly "digital" RGB in that each red/green/blue value can only be a logical 1 or a 0. The drive transistors most likely won't accept anything other than a high or low signal, so anything that goes up to 0.7 volts might not turn those transistors on fully, and that rules out injection in the "right" place.

Your best bet is to find another display.

Closed 2024-11-01.

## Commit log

2024-04-28 well that's a year of effort and a lot of $ wasted
    [tv desecrator-B_Cu.gbr, tv desecrator-B_Mask.gbr, tv desecrator-B_Paste.gbr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]
2024-04-28 add schematic images
2025-03-14 document hot chassis now that i've learned about them
